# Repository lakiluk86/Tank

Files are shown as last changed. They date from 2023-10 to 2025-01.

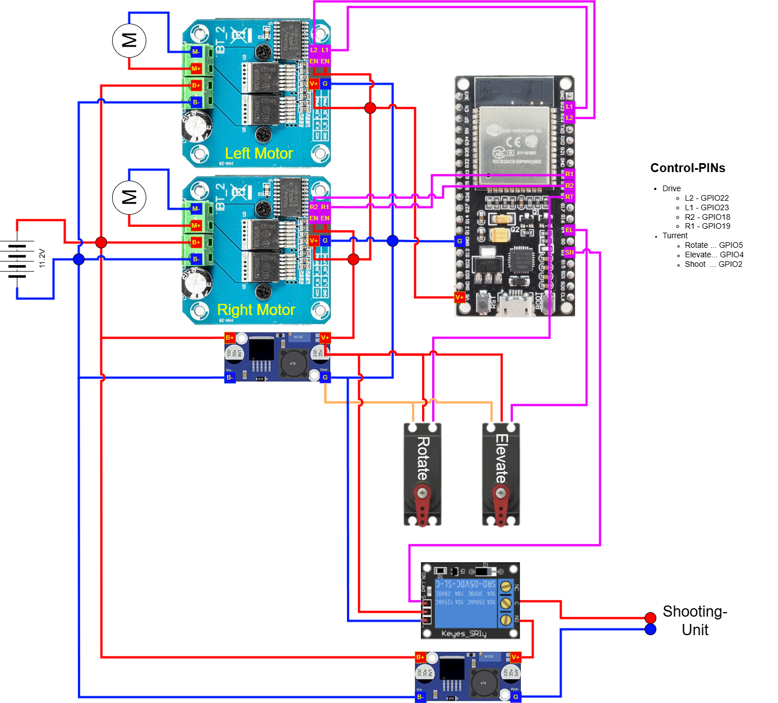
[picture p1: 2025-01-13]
doc/Schematics.png

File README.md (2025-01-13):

# Soviet Tank KV-1
This project realizes a RC tank, controlled by a PS4-Controller. As the controller in the tank, a ESP32-NodeMCU board is used. A 3D-print project from Thingiverse was modified to enable the tank to shoot.
## 3D Print
- All the parts for 3D printing can be obtained on Thingiverse, https://www.thingiverse.com/thing:5069466
- If one wants to enable the tank to shoot the files for printing the adapter for the shooting unit is included in the doc directory
  - see pictures in doc directory for where to put the prints, should be self explanatory
  - Closure.3mf is for closing the hole you drill in the hull on top of the tank for inserting the BB bullets
  - for attaching the adapter 2x M2x5 screws are needed
## Bluetooth
- For BT functionality the lib https://github.com/aed3/PS4-esp32 is used. But watch out, it is not working with newer versions of the arduino framework. So there is a local copy in the project which was modified according to https://www.youtube.com/watch?v=dRysvxQfVDw
- For working bluetooth one has to set the master MAC address of the PS4-Controller to the one specified in the code. This can be done by the tool "SixAxisPairTool" for example.
- Furthermore all BT connections of the ESP have to be resettet before pairing is possible to the ESP. This is done automatically in the code.
## Electronics
- ESP32-NodeMCU
- 2x BTS7960 Dual H-Bridge Motor Driver
- 2x LM2596S Step down converter
- LiPo 11.2V battery
- Relais for driving the shooting unit
- The servo for rotating the turrent was modified so that it can turn endless (see https://youtu.be/JhHSXCLsN4k?si=Jbtp7p6A8w-mFTv1 for example)
- Shooting unit for HengLong tanks V6 with barrel recoil, see also picture in doc directory
  - the shaft at the rear end of the unit has to be removed, so that the unit fits in the turrent when barrel is pointing downwards
## Controls on PS4-Controller
- L2/R2 for driving left/right track forward
- L1/R1 for driving left/right track backward
- Right joystick for adjusting turrent
  - x-Axis is rotating
  - y-Axis is elevation
- Up/Down Buttons for fine adjustments of elevation
- Left/Right Buttons for fine adjustments of rotation
- X for shooting

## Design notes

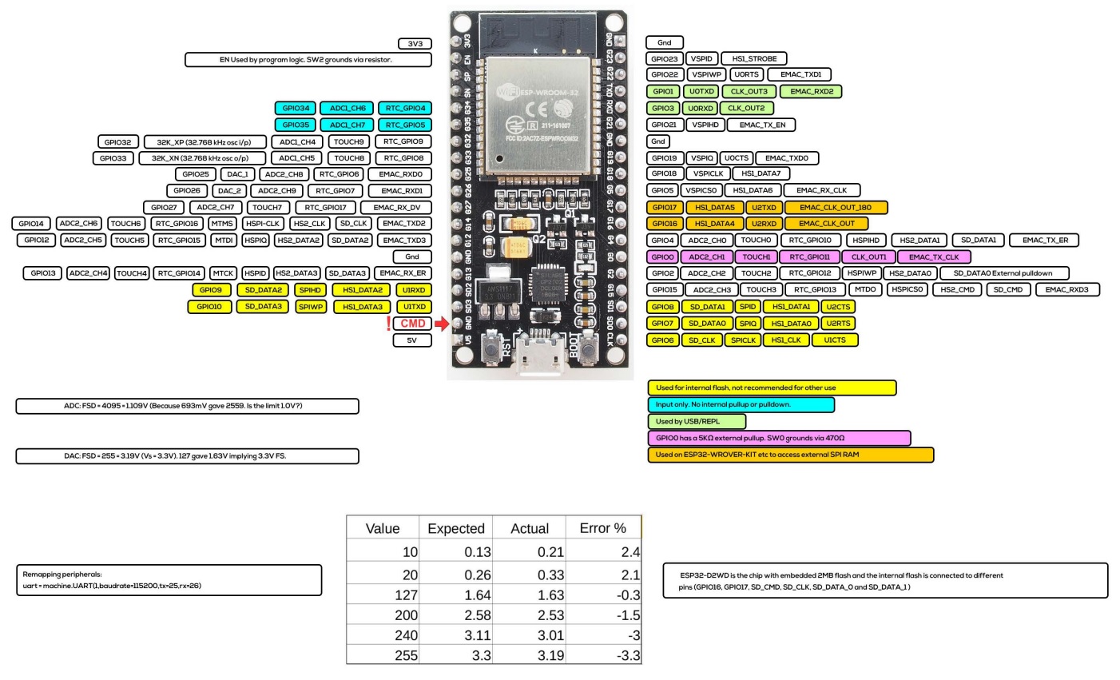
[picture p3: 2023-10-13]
doc/ESP32-NodeMCU-AZDelivery.jpg

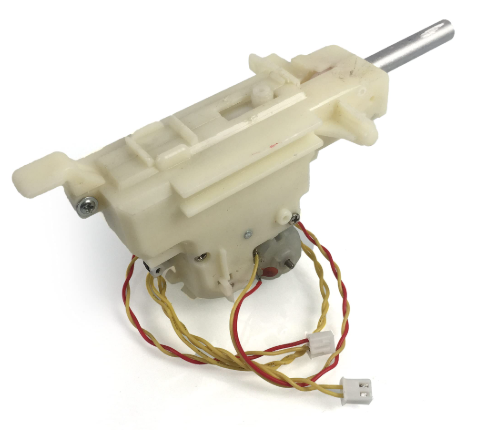
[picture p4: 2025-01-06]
doc/ShootingUnit.PNG

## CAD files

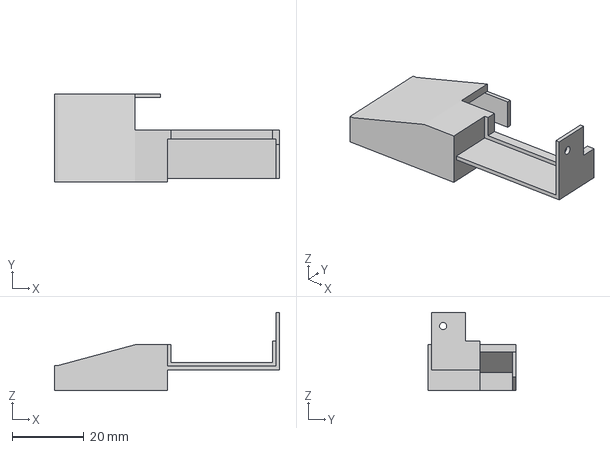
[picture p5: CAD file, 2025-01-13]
doc/3D-Print/Magazine.3mf
62.7 x 24.5 x 21.8 mm

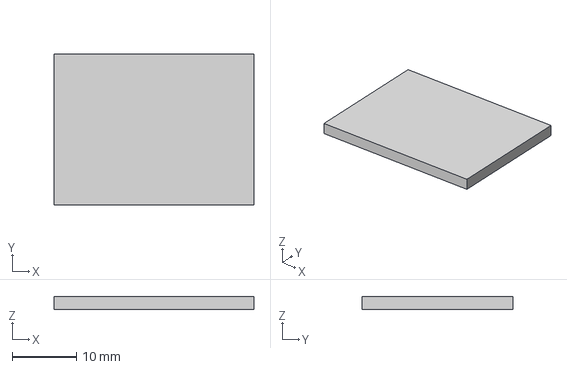
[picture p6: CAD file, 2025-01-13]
doc/3D-Print/Magazine_Top.3mf
31.2 x 23.5 x 2.00 mm

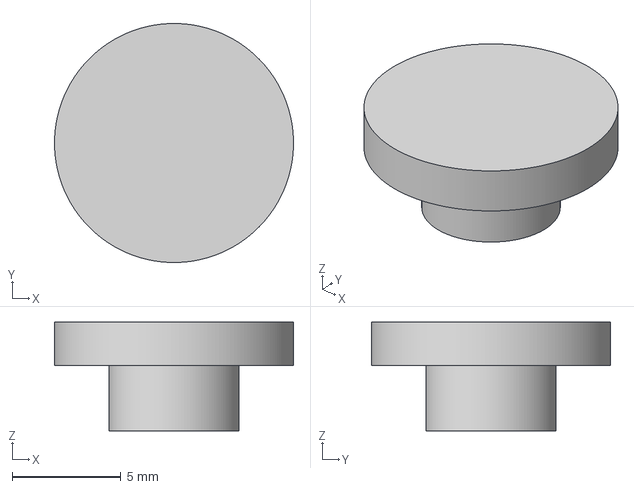
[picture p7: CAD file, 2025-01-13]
doc/3D-Print/Closure.3mf
11.0 x 11.0 x 5.00 mm

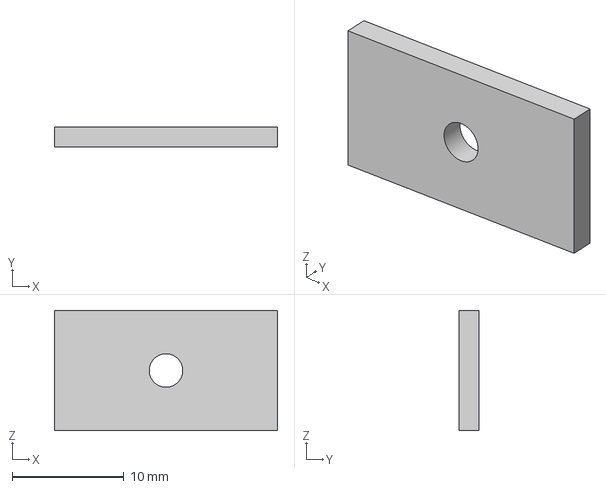
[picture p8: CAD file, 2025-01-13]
doc/3D-Print/Interface_ShootingUnit2.3mf
20.0 x 1.80 x 10.8 mm

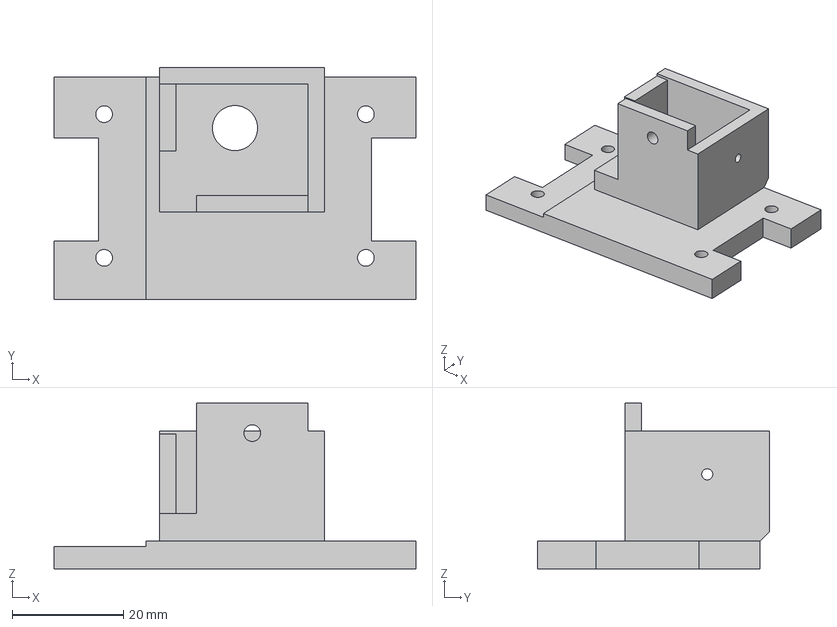
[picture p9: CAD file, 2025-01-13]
doc/3D-Print/Interface_ShootingUnit1.3mf
65.0 x 41.7 x 29.8 mm

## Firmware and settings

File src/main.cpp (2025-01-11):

#include <Arduino.h>
#include <PS4Controller.h>
#include "esp_gap_bt_api.h"

//GPIO definitions
const uint8_t MOTOR_L_1_GPIO = 23;
const uint8_t MOTOR_L_2_GPIO = 22;
const uint8_t MOTOR_R_1_GPIO = 19;
const uint8_t MOTOR_R_2_GPIO = 18;
const uint8_t TURRENT_ROTATE_GPIO = 5;
const uint8_t TURRENT_ELEVATE_GPIO = 4;
const uint8_t TURRENT_SHOOT_GPIO = 2;

//machine settings
const uint8_t MAX_DRIVE_SPEED_L = 85;  //maximum drive speed left track (duty cycle, absolut maximum is 255)
const uint8_t MAX_DRIVE_SPEED_R = 85;  //maximum drive speed right track (duty cycle, absolut maximum is 255)
const uint8_t DRIVE_SPEED_BACK_L = 70; //fixed speed for driving backwards left track (duty cycle, absolut maximum is 255)
const uint8_t DRIVE_SPEED_BACK_R = 70; //fixed speed for driving backwards right track (duty cycle, absolut maximum is 255)
const uint16_t TURRENT_ROTATE_STOP = 305; //duty cycle for middle position of servo for rotating turrent
const uint8_t DRIVE_JOY_DEATHBAND = 40; //deathband of left joystick axis for driving
const uint8_t TURRENT_JOY_DEATHBAND = 50; //deathband of right joystick axis for rotating and elevating turrent
const uint16_t TURRENT_ELEVATE_MIN = 106; //minimum duty cycle for turrent elevation
const uint16_t TURRENT_ELEVATE_MAX = 435; //maximum duty cycle for turrent elevation
const uint16_t TURRENT_ELEVATE_DFLT = TURRENT_ELEVATE_MIN + (TURRENT_ELEVATE_MAX - TURRENT_ELEVATE_MIN) / 2;

//PWM settings for drive control and servos
const uint8_t MOTOR_L_1_PWM_CHANNEL = 0;
const uint8_t MOTOR_L_2_PWM_CHANNEL = 1;
const uint8_t MOTOR_R_1_PWM_CHANNEL = 2;
const uint8_t MOTOR_R_2_PWM_CHANNEL = 3;
const uint8_t TURRENT_ROTATE_PWM_CHANNEL = 4;
const uint8_t TURRENT_ELEVATE_PWM_CHANNEL = 5;
const uint32_t PWM_FREQ_DRIVE = 30000; //pwm frequency for drive control
const uint8_t PWM_FREQ_SERVO = 50; //pwm frequency for servos
const uint8_t PWM_RESOLUTION_DRIVE = 8; //max duty cycle is 255 because of this resolution
const uint8_t PWM_RESOLUTION_SERVO = 12; //max duty cycle is 4095 because of this resolution

//Commands for driving and servos (pwm duty cycle)
uint8_t driveCmdLeft = 0;
uint8_t driveCmdRight = 0;
int8_t driveDirLeft = 0;
int8_t driveDirRight = 0;
uint16_t turrentRotateCmd = 0;
uint16_t turrentElevateCmd = TURRENT_ELEVATE_DFLT;
long rotateLeftTimestamp = 0;
long rotateRightTimestamp = 0;
bool turrentRotateLeft = false;
bool turrentRotateRight = false;
long elevationTimestamp = 0;
bool turrentElevateUp = false;
bool turrentElevateDown = false;
uint8_t shootCmd = LOW;

//BT settings and status
const char* BT_MAC = "7c:9e:bd:06:28:7a";
bool controller_connected = false;

//unbinds all BT devices
void unbindAllBT() {
  uint8_t pairedDeviceBtAddr[20][6];  
  int count = esp_bt_gap_get_bond_device_num();
  esp_bt_gap_get_bond_device_list(&count, pairedDeviceBtAddr);
  for(int i = 0; i < count; i++) 
  {
    esp_bt_gap_remove_bond_device(pairedDeviceBtAddr[i]);
  }
  Serial.println("Unbound all BT devices");
}

//ESP32 setup function
void setup() {
  Serial.begin(115200); //setup serial monitor
  
  PS4.begin(BT_MAC);  //setup BT on MAC adress which is predefined on controller by SixAxisPairTool
  unbindAllBT();  //unbind all earlier BT devices

  //init pwm outputs drive and servos
  ledcSetup(MOTOR_L_1_PWM_CHANNEL, PWM_FREQ_DRIVE, PWM_RESOLUTION_DRIVE);
  ledcSetup(MOTOR_L_2_PWM_CHANNEL, PWM_FREQ_DRIVE, PWM_RESOLUTION_DRIVE);
  ledcSetup(MOTOR_R_1_PWM_CHANNEL, PWM_FREQ_DRIVE, PWM_RESOLUTION_DRIVE);
  ledcSetup(MOTOR_R_2_PWM_CHANNEL, PWM_FREQ_DRIVE, PWM_RESOLUTION_DRIVE);
  ledcSetup(TURRENT_ROTATE_PWM_CHANNEL, PWM_FREQ_SERVO, PWM_RESOLUTION_SERVO);
  ledcSetup(TURRENT_ELEVATE_PWM_CHANNEL, PWM_FREQ_SERVO, PWM_RESOLUTION_SERVO);
  ledcAttachPin(MOTOR_L_1_GPIO, MOTOR_L_1_PWM_CHANNEL);
  ledcAttachPin(MOTOR_L_2_GPIO, MOTOR_L_2_PWM_CHANNEL);
  ledcAttachPin(MOTOR_R_1_GPIO, MOTOR_R_1_PWM_CHANNEL);
  ledcAttachPin(MOTOR_R_2_GPIO, MOTOR_R_2_PWM_CHANNEL);
  ledcAttachPin(TURRENT_ROTATE_GPIO, TURRENT_ROTATE_PWM_CHANNEL);
  ledcAttachPin(TURRENT_ELEVATE_GPIO, TURRENT_ELEVATE_PWM_CHANNEL);

  //setup shooting output pin
  pinMode(TURRENT_SHOOT_GPIO, OUTPUT);

  Serial.println("Waiting for connection of PS4 controller...");
}

//calc drive command from L2 or R2 value
uint8_t getDriveCommand(uint8_t axis, uint8_t maxDriveSpeed) {
  return map(axis, 0, 255, 0, maxDriveSpeed);
}

//command motor driver
void commandMotor(uint8_t driveCmd, int8_t driveDir, uint8_t motorPWM1, uint8_t motorPWM2) {
  //set direction
  switch (driveDir)
  {
    case 1:
      //drive forward
      ledcWrite(motorPWM1, driveCmd);
      ledcWrite(motorPWM2, 0);
      break;
      
    case -1:
      //drive backwards
      ledcWrite(motorPWM1, 0);
      ledcWrite(motorPWM2, driveCmd);
      break;

    default:
      //stop drive
      ledcWrite(motorPWM1, 0);
      ledcWrite(motorPWM2, 0);
      break;
  }
}

//main program loop
void loop() {
  driveCmdLeft = 0;
  driveCmdRight = 0;
  driveDirLeft = 0;
  driveDirRight = 0;
  shootCmd = LOW;
  turrentRotateCmd = TURRENT_ROTATE_STOP;

  //check first BT connection of controller
  if (PS4.isConnected() && controller_connected == false) {
    Serial.println("Controller connected");
    controller_connected = true;
  }

  //check axis on controller
  if (PS4.isConnected() && controller_connected == true){

    //check drive controls (driving is done by L1/2 and R1/2)
    if (PS4.L2()){
      driveCmdLeft = getDriveCommand(PS4.L2Value(), MAX_DRIVE_SPEED_L);
      driveDirLeft = -1;
    }
    if (PS4.L1()){
      driveCmdLeft = DRIVE_SPEED_BACK_L;
      driveDirLeft = 1;
    }
    if (PS4.R2()){
      driveCmdRight = getDriveCommand(PS4.R2Value(), MAX_DRIVE_SPEED_R);
      driveDirRight = 1;
    }
    if (PS4.R1()){
      driveCmdRight = DRIVE_SPEED_BACK_R;
      driveDirRight = -1;
    }

    //check turrent control rotation by right joystick
    if (abs(PS4.RStickX()) >= TURRENT_JOY_DEATHBAND){
      //this servo has a very narrow working duty cycle because of modification to endless servo movement
      turrentRotateCmd = map(PS4.RStickX(), -127, 127, TURRENT_ROTATE_STOP + 10, TURRENT_ROTATE_STOP - 10);
    }

    //check turrent control rotation by left/right buttons for fine controlling
    if (PS4.Left() || (millis() - rotateLeftTimestamp < 250)){
      if(turrentRotateLeft == false){
        turrentRotateCmd = TURRENT_ROTATE_STOP + 4;
        rotateLeftTimestamp = millis();
        turrentRotateLeft = true;
      }
      if(millis() - rotateLeftTimestamp < 250){
        turrentRotateCmd = TURRENT_ROTATE_STOP + 4;
      }
    }
    else {
      turrentRotateLeft = false;
    }
    if (PS4.Right() || (millis() - rotateRightTimestamp < 250)){
      if(turrentRotateRight == false){
        turrentRotateCmd = TURRENT_ROTATE_STOP - 4;
        rotateRightTimestamp = millis();
        turrentRotateRight = true;
      }
      if(millis() - rotateRightTimestamp < 250){
        turrentRotateCmd = TURRENT_ROTATE_STOP - 4;
      }
    }
    else {
      turrentRotateRight = false;
    }

    //check turrent control elevation by right joystick
    if (abs(PS4.RStickY()) >= TURRENT_JOY_DEATHBAND && (millis() - elevationTimestamp > 15)){
      if (PS4.RStickY() > 0){
        turrentElevateCmd++;
      }
      else {
        turrentElevateCmd--;
      }
      turrentElevateCmd = min(turrentElevateCmd, TURRENT_ELEVATE_MAX);
      turrentElevateCmd = max(turrentElevateCmd, TURRENT_ELEVATE_MIN);
      elevationTimestamp = millis();
    }

    //check turrent control elevation by up/down buttons for fine controlling
    if (PS4.Up()){
      if(turrentElevateUp == false){
        turrentElevateCmd += 4;
        turrentElevateUp = true;
      }
    }
    else {
      turrentElevateUp = false;
    }
    if (PS4.Down()){
      if(turrentElevateDown == false){
        turrentElevateCmd -= 4;
        turrentElevateDown = true;
      }
    }
    else {
      turrentElevateDown = false;
    }

    //check shooting control
    if (PS4.Cross()){
      shootCmd = HIGH;
    }
  }

  //command drive motors
  commandMotor(driveCmdLeft, driveDirLeft, MOTOR_L_1_PWM_CHANNEL, MOTOR_L_2_PWM_CHANNEL);
  commandMotor(driveCmdRight, driveDirRight, MOTOR_R_1_PWM_CHANNEL, MOTOR_R_2_PWM_CHANNEL);

  //command servos
  ledcWrite(TURRENT_ROTATE_PWM_CHANNEL, turrentRotateCmd);
  ledcWrite(TURRENT_ELEVATE_PWM_CHANNEL, turrentElevateCmd);

  //command shooting
  digitalWrite(TURRENT_SHOOT_GPIO, shootCmd);
}

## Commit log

2024-12-09 Add schematics
2024-12-12 new motor controller board
2024-12-12 sync control, higher pwm
2024-12-15 new schematics
2024-12-15 new schematics finished
2024-12-15 new motor control
2024-12-20 new motor controller
2025-01-13 add 3d prints
    [Closure.3mf, Interface_ShootingUnit1.3mf, Interface_ShootingUnit2.3mf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]
